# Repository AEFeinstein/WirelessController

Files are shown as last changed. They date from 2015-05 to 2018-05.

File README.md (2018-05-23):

View this project on [CADLAB.io](https://cadlab.io/project/1074). 

# WirelessController
WirelessController is an ATmega328p based video game controller that controls a [PixelShirtV2](https://github.com/AEFeinstein/PixelShirtV2), which is Arduino based collection of games, using an nRF24L01+ wireless radio.

## The Firmware

The firmware is relatively simple. The main function initializes the hardware and calibrates the joystick. An infinite loop polls the digital buttons and analog X & Y values of the joystick. If any of the values change, a bitpacked message containing the controller's state is sent to the PixelShirtV2.

A timer interrupt is called once a second to toggle a heartbeat LED.

Each controller's ID must be hardcoded differently when compiling and flashing the firmware. The PixelShirtV2 can support up to four controllers simultaneously.

This project uses the [nrf24L01+ radio library](https://github.com/kehribar/nrf24L01_plus).

## The Hardware

The controller is powered by two AA batteries, which make nice grips on the bottom. The ATmega328p is populated underneath the PCB. The 3x2 header is an ISP header, and the 6x1 header is for serial debug over an FTDI cable.

I populated one of the controllers with red LEDs, and the other with blue LEDs. These are conveniently the two player colors used in all games, which made identifying player one and player two very easy.

Screenshots of the PCB layout. The top view is first, then the bottom view.
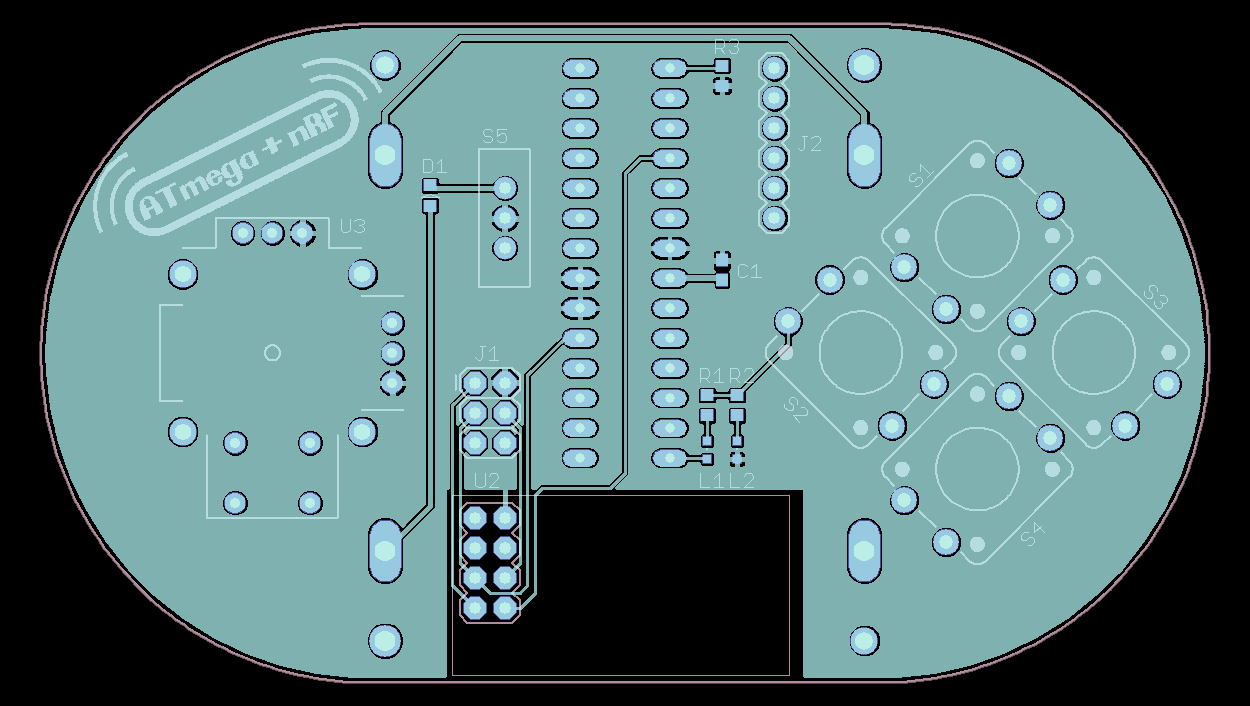
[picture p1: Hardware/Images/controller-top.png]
<br>
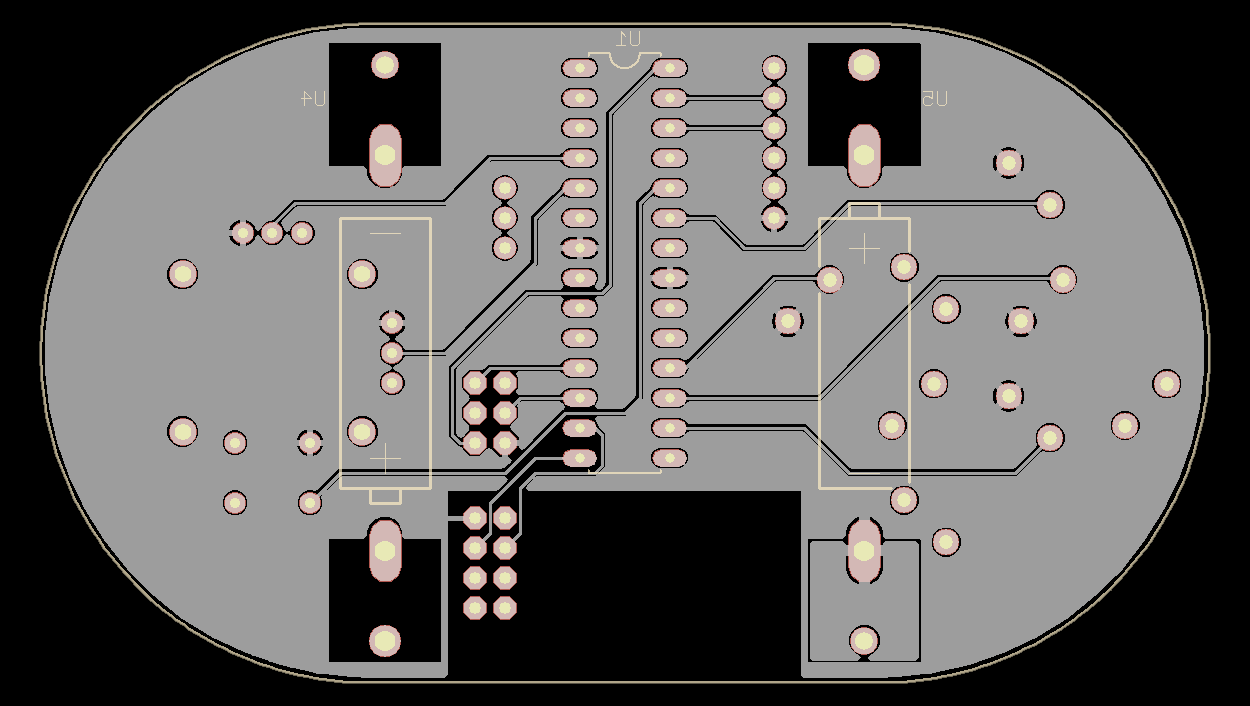
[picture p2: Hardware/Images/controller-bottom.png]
<br>

This is what it looks like all soldered together.
<br>

## Thanks
3D models and print courtesy of [gbsoares](https://github.com/gbsoares).<br>
[jgordo32](https://github.com/jgordo32) assisted with hardware design.

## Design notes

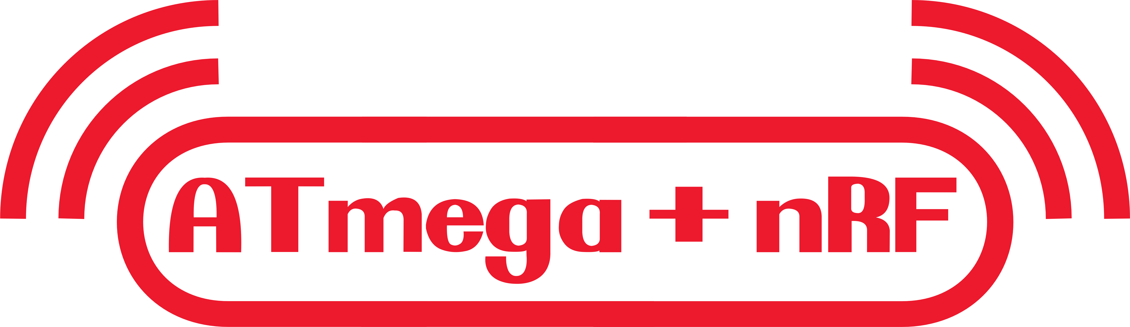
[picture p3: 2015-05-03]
Hardware/nintendo.png

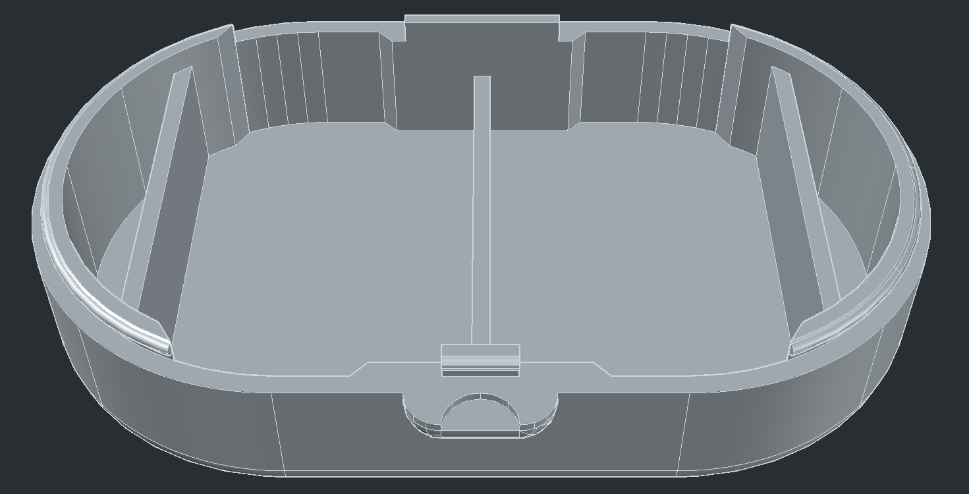
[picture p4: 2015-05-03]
Enclosure/Renderings/bottom1.png

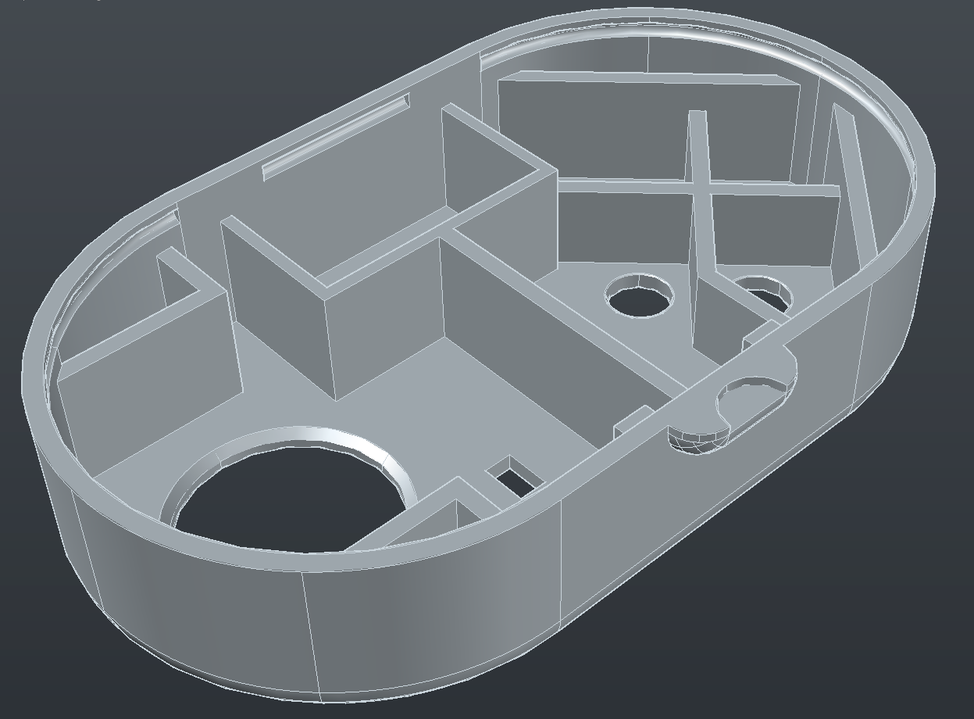
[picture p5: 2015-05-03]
Enclosure/Renderings/top3.png

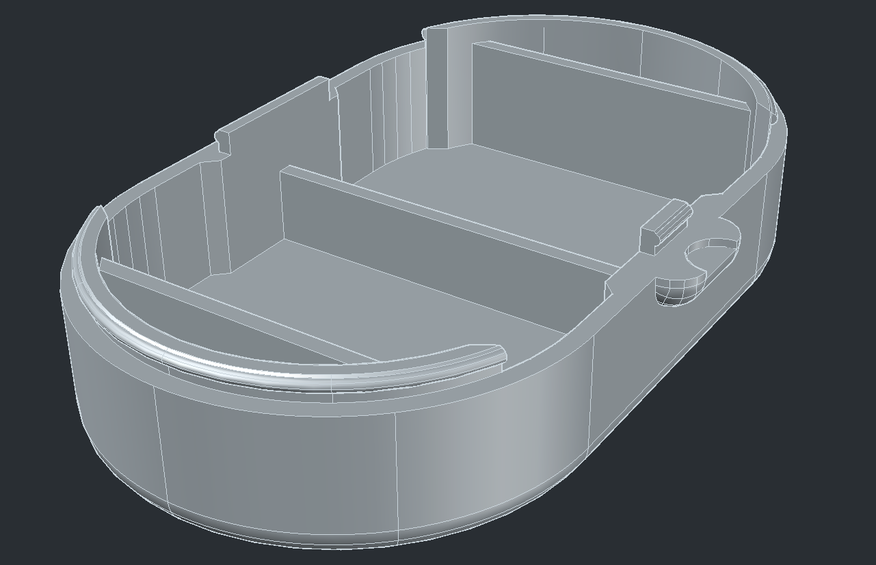
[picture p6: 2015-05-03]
Enclosure/Renderings/bottom2.png

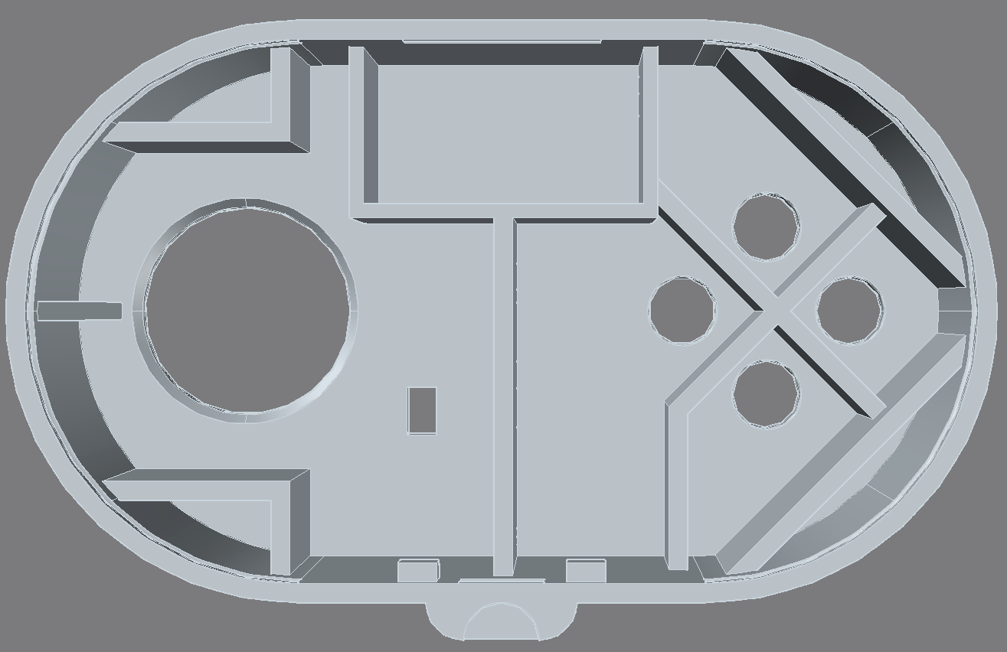
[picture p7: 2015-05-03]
Enclosure/Renderings/top2.png

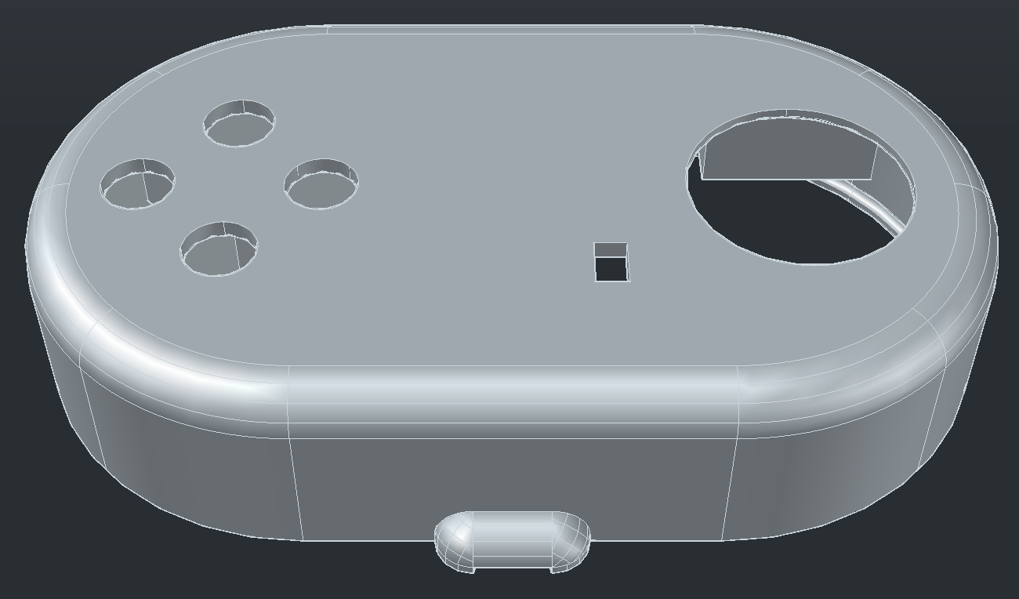
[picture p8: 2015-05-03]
Enclosure/Renderings/top1.png

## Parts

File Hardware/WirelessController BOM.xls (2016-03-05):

Cost | Quantity | Description | PCB Reference | Part Number | Link
$0.24 | 1 | DIL VERTICAL PC TAIL PIN HEADER, 3x2 | J1 | 952-2121-ND | https://www.digikey.com/product-detail/en/harwin-inc/M20-9980346/952-2121-ND/3728085
$0.24 | 1 | SIL VERTICAL PC TAIL PIN HEADER, 6x1 | J2 | 952-2270-ND | https://www.digikey.com/product-detail/en/harwin-inc/M20-9990646/952-2270-ND/3728234
$0.10 | 2 | RES SMD 30 OHM 5% 1/10W 0603 | R1, R2 | P30GCT-ND | https://www.digikey.com/product-detail/en/panasonic-electronic-components/ERJ-3GEYJ300V/P30GCT-ND/134671
$0.17 | 1 | RES SMD 4.7K OHM 1% 1/8W 0603 | R3 | MCT0603-4.70K-CFCT-ND | https://www.digikey.com/product-detail/en/vishay-beyschlag/MCT06030C4701FP500/MCT0603-4.70K-CFCT-ND/2607907
$0.38 | 2 | LED BLUE DIFFUSED 0603 SMD | L1. L2 | 475-2816-1-ND | https://www.digikey.com/product-detail/en/osram-opto-semiconductors-inc/LB%20Q39G-L2OO-35-1/475-2816-1-ND/2176355
$0.10 | 1 | CAP CER 0.1UF 16V X7R 0603 | C1 | 490-1532-1-ND | https://www.digikey.com/product-detail/en/murata-electronics-north-america/GRM188R71C104KA01D/490-1532-1-ND/587771
$0.52 | 1 | DIODE SCHOTTKY 40V 30MA 0603 | D1 | CD0603-B00340CT-ND | https://www.digikey.com/product-detail/en/bourns-inc/CD0603-B00340/CD0603-B00340CT-ND/3534223
$3.70 | 1 | IC MCU 8BIT 32KB FLASH 28PDIP | U1 | ATMEGA328P-PU-ND | https://www.digikey.com/product-detail/en/atmel/ATMEGA328P-PU/ATMEGA328P-PU-ND/1914589
$2.90 | 1 | NRF24L01+MODULE | U2 | 1597-1352-ND | https://www.digikey.com/product-detail/en/seeed-technology-ltd/113990011/1597-1352-ND/5488251
$3.95 | 1 | Thumb Joystick | U3 | COM-09032 | https://www.sparkfun.com/products/9032
$0.50 | 2 | Battery Holder - 1xAA (PTH) | U4, U5 | PRT-07949 | https://www.sparkfun.com/products/7949
$0.50 | 4 | Momentary Pushbutton Switch - 12mm Square | S1, S2, S3, S4 | COM-09190 | https://www.sparkfun.com/products/9190
$1.50 | 1 | SPDT Mini Power Switch | S5 | COM-00102 | https://www.sparkfun.com/products/102
$4.00 | 1 | Wireless Controller PCB |  |  | https://github.com/AEFeinstein/WirelessController/tree/master/Hardware
$21.28

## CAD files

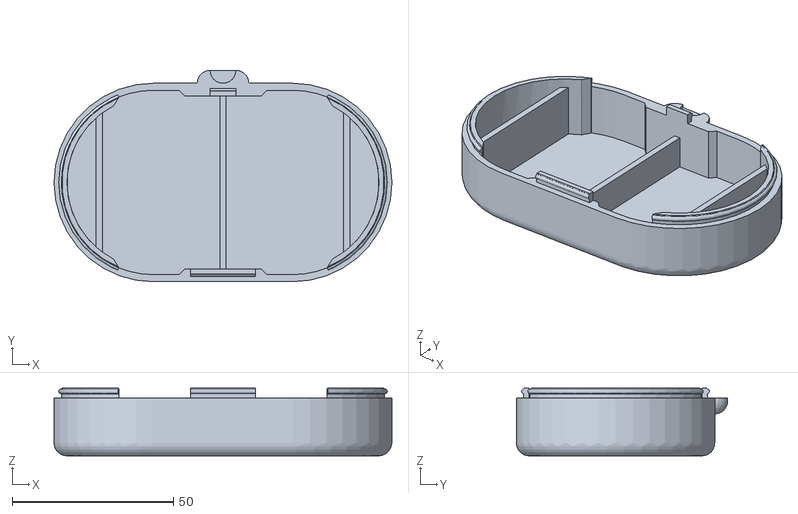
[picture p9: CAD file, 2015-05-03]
Enclosure/3D print/bottom.stl
104.7 x 65.5 x 21.0

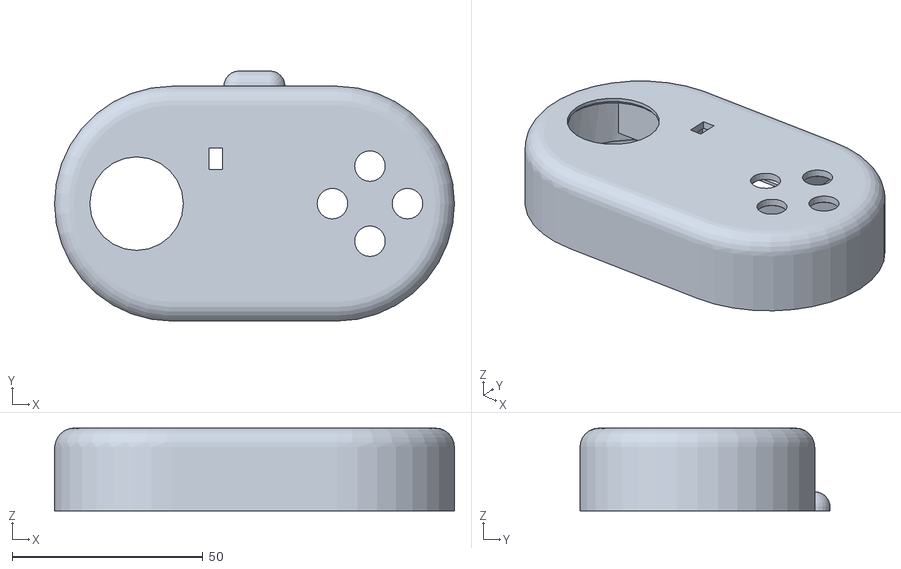
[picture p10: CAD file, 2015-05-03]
Enclosure/3D print/top.stl
104.7 x 65.5 x 21.7

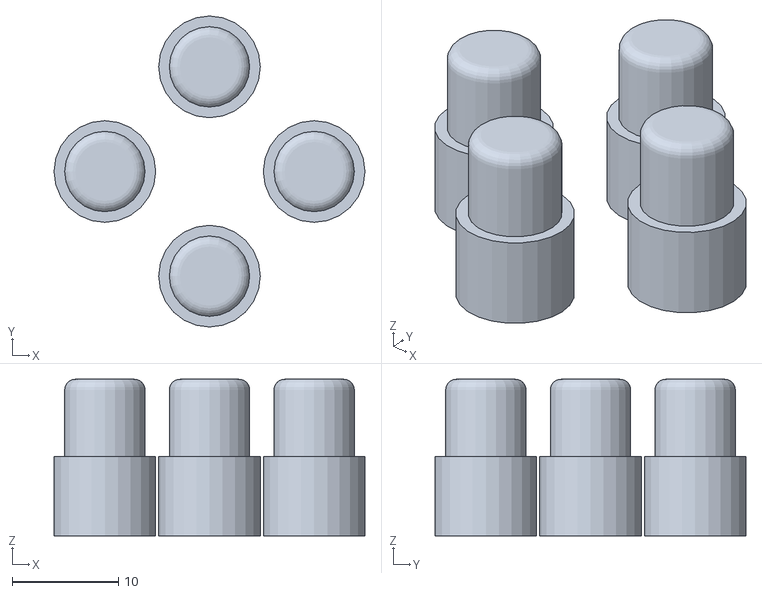
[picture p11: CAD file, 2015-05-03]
Enclosure/3D print/buttons.stl
29.2 x 29.2 x 14.7

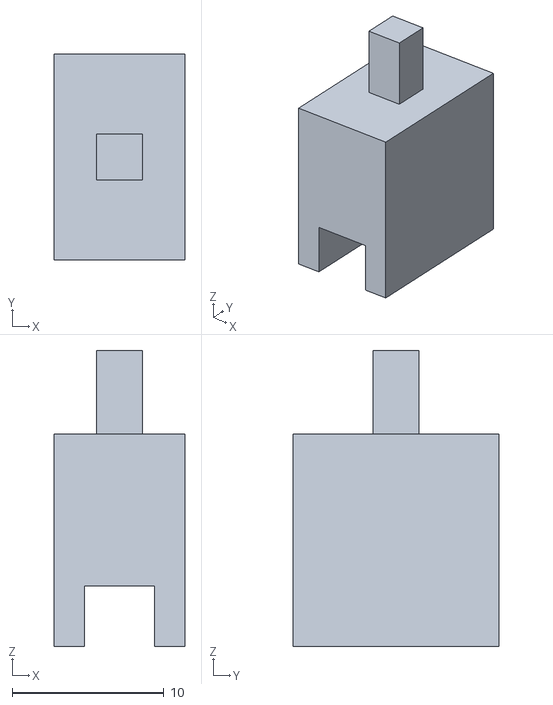
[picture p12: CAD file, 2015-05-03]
Enclosure/3D print/switch.stl
8.60 x 13.6 x 19.5

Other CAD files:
Enclosure/controller_case.dwg

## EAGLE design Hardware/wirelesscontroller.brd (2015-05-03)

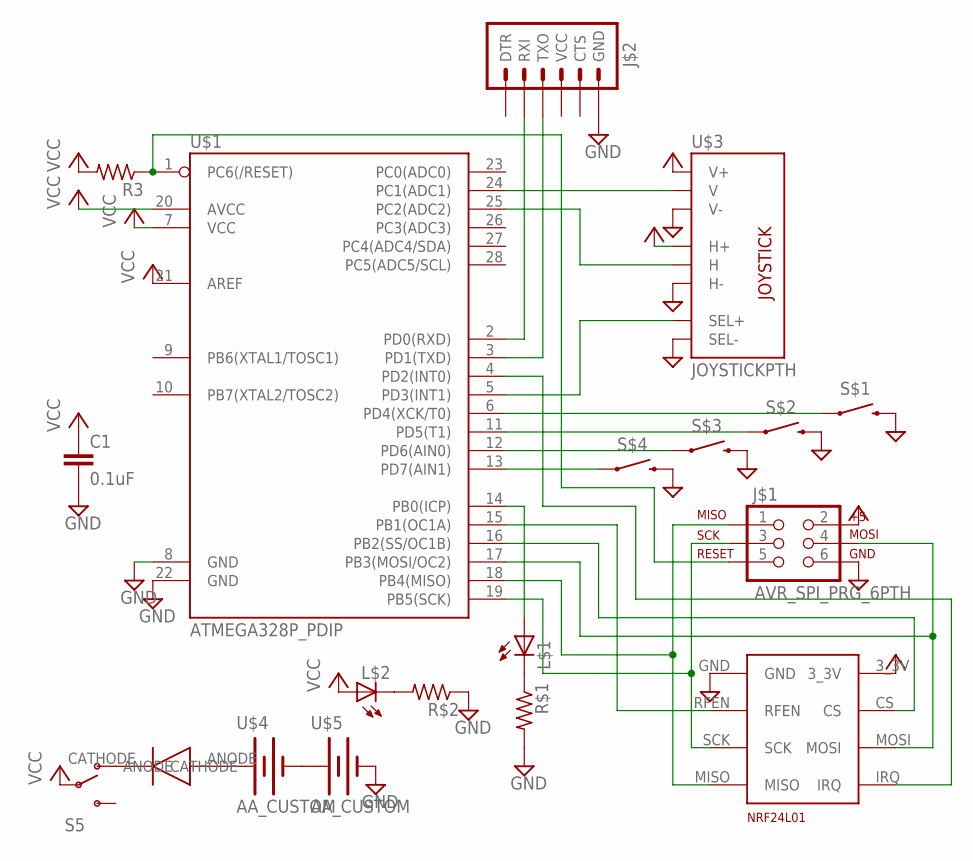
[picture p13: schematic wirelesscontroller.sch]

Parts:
C1: 0.1uF; 0603-CAP
D$1: DIODE; R0603
J$1: AVR_SPI_PRG_6PTH; 2X3
J$2: ARDUINO_SERIAL_PROGRAMPTH; 1X06
L$1, L$2: LEDCHIPLED_0603; CHIPLED_0603
R3: R-US_R0603; R0603
R$1, R$2: R-US_R0603; R0603
S5: SWITCH-SPDTPTH; SWITCH-SPDT
S$1, S$2, S$3, S$4: SWITCH-MOMENTARY-212MM; TACTILE-PTH-12MM
U$1: ATMEGA328P_PDIP; DIL28-3
U$2: NRF24L01_BRK; 4X2
U$3: JOYSTICKPTH; JOYSTICK
U$4, U$5: AA_CUSTOM; AACLIP

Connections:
AX: U$1.25 (PC2(ADC2)), U$3.H2 (H)
AY: U$1.24 (PC1(ADC1)), U$3.V2 (V)
B1: S$1.1, U$1.6 (PD4(XCK/T0))
B2: S$2.1, U$1.11 (PD5(T1))
B3: S$3.1, U$1.12 (PD6(AIN0))
B4: S$4.1, U$1.13 (PD7(AIN1))
B5: U$1.5 (PD3(INT1)), U$3.B1A (SEL+)
CS: U$1.16 (PB2(SS/OC1B)), U$2.CS
GND: C1.2, J$1.6, J$2.6 (GND), R$1.2, R$2.1, S$1.3 (2), S$2.3 (2), S$3.3 (2), S$4.3 (2), U$1.8 (GND), U$1.22 (GND), U$2.GND, U$3.B2A (SEL-), U$3.H3 (H-), U$3.V3 (V-), U$5.-
MISO: J$1.1, U$1.18 (PB4(MISO)), U$2.MISO
MOSI: J$1.4, U$1.17 (PB3(MOSI/OC2)), U$2.MOSI
unnamed: D$1.CATHODE, S5.1 (O)
unnamed: U$4.-, U$5.+
unnamed: D$1.ANODE, U$4.+
unnamed: L$2.C, R$2.2
unnamed: L$1.C, R$1.1
unnamed: L$1.A, U$1.14 (PB0(ICP))
RESET: J$1.5, R3.1, U$1.1 (PC6(/RESET))
RFEN: U$1.15 (PB1(OC1A)), U$2.RFEN
RF_IRQ: U$1.4 (PD2(INT0)), U$2.IRQ
RX: J$2.2 (RXI), U$1.2 (PD0(RXD))
SCK: J$1.3, U$1.19 (PB5(SCK)), U$2.SCK
TX: J$2.3 (TXO), U$1.3 (PD1(TXD))
VCC: C1.1, J$1.2, L$2.A, R3.2, S5.2, U$1.7 (VCC), U$1.20 (AVCC), U$1.21 (AREF), U$2.3_3V, U$3.H1 (H+), U$3.V1 (V+)

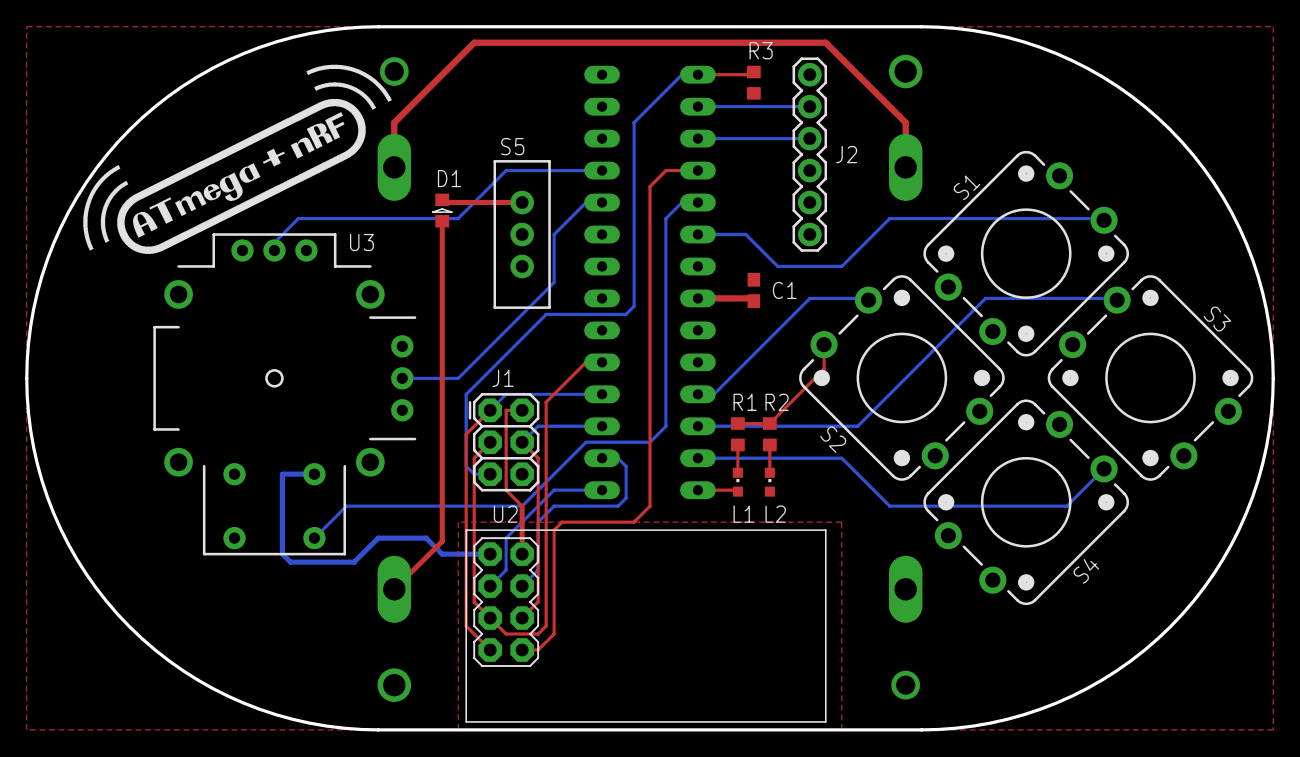
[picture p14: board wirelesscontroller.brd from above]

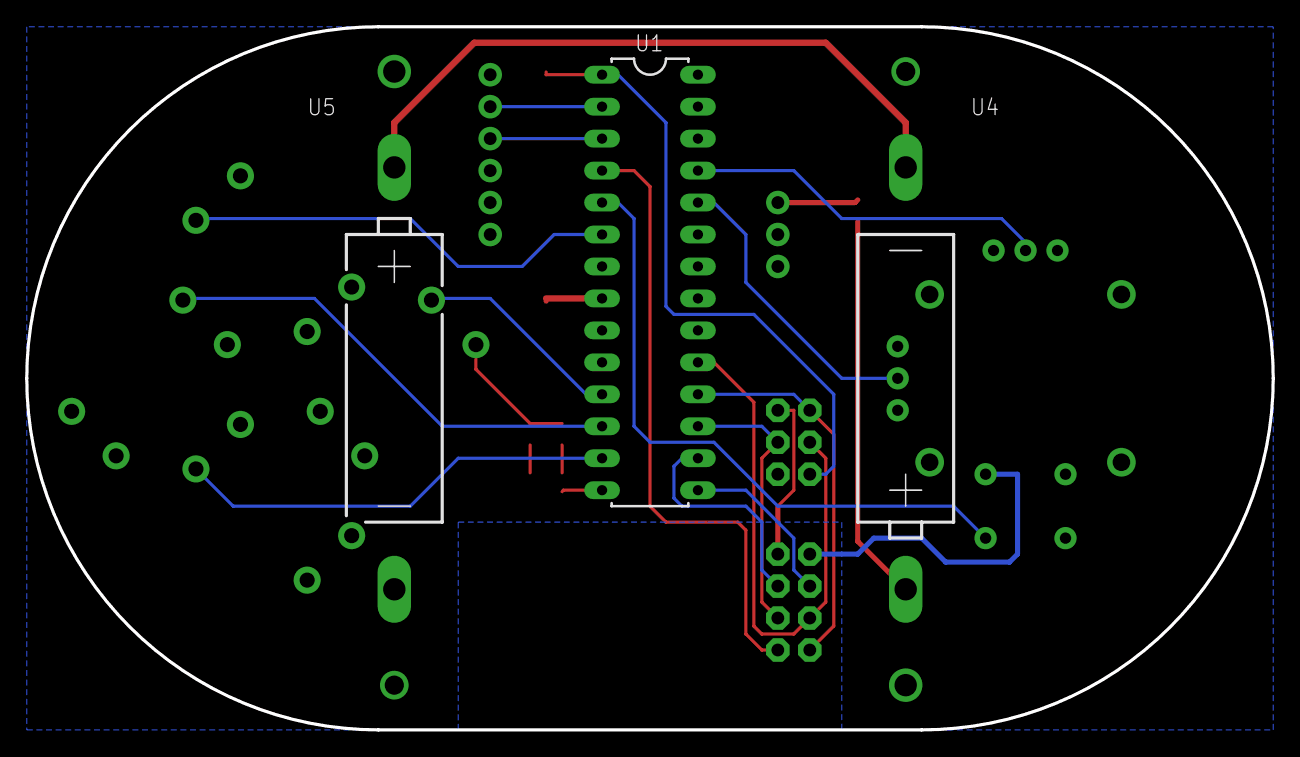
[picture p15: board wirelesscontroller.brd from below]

Board: 2 copper layers, 99.1 x 55.9 mm, 19 parts (3 on the bottom side), 24 nets.

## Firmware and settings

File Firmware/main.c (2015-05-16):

/**
 * Copyright 2011 Adam Feinstein
 *
 * This file is part of WirelessController.
 *
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
 * You should have received a copy of the GNU General Public License
 * along with WirelessController.  If not, see <http://www.gnu.org/licenses/>.
 */

#include <stdint.h>

#include "main.h"
#include "gpio.h"
#include "nrf24.h"
#include "timer.h"
#if DBG_PRINT == ENABLED
#include "uart.h"
#include <util/delay.h>
#include <string.h>
#include <stdlib.h>
#endif

/* Number of ADC reads taken to calibrate the ADC's middle position */
#define NUM_CALIBRATIONS 10

int main(void)
{
  /* All the controller state is stored in 32 bits */
  uint32_t inputState, oldInputState;

  /* Used for calibrating the ADC */
  uint32_t xJoystickCenter, yJoystickCenter;
  uint8_t i;

  #if DBG_PRINT == ENABLED
  uint8_t msgStatus;
  char dbgstr[100];
  #endif

  /* Initialize everything */
  gpio_init();
  nrf24_init();
  timer_init();
  #if DBG_PRINT == ENABLED
  init_uart();
  #endif

  /* Calibrate joystick center */
  xJoystickCenter = 0;
  yJoystickCenter = 0;
  for(i = 0; i < NUM_CALIBRATIONS; i++) {
    analog_read(&inputState, 0, 0);
    xJoystickCenter += GET_X_AXIS(inputState);
    yJoystickCenter += GET_Y_AXIS(inputState);
  }
  xJoystickCenter /= NUM_CALIBRATIONS;
  yJoystickCenter /= NUM_CALIBRATIONS;

  /* Set an ID to differentiate controllers. Must be compiled differently for controllers 1-4 */
  /* SET_PLAYER(inputState, 0); */
  SET_PLAYER(inputState, 1);
  /* SET_PLAYER(inputState, 2); */
  /* SET_PLAYER(inputState, 3); */

  /* Main Loop */
  while (1) {

    /* Save the prior state */
    oldInputState = inputState;

    /* Read Controller State */
    digital_read(&inputState);
    analog_read(&inputState, xJoystickCenter, yJoystickCenter);

    /* If any inputs have changed, send an RF message */
    if(oldInputState != inputState) {

      /* Send the controller's state. Automatically goes to TX mode */
      nrf24_send((uint8_t*)(&inputState));

      while(nrf24_isSending()) {
        ;/* Wait for transmission to end */
      }

      #if DBG_PRINT == ENABLED
      /* Make analysis on last transmission attempt */
      msgStatus = nrf24_lastMessageStatus();

      if(msgStatus == NRF24_TRANSMISSON_OK) {
        USART_putstring("transmission went OK\n");
      }
      else if(msgStatus == NRF24_MESSAGE_LOST) {
        USART_putstring("Message is lost\n");
      }

      /* Retransmission count indicates the transmission quality */
      msgStatus = nrf24_retransmissionCount();
      USART_putstring("Retransmission count: ");
      itoa(msgStatus, dbgstr, 16);
      USART_putstring(dbgstr);
      USART_putstring("\n");

      /* Print the analog stick position */
      itoa(GET_X_AXIS(inputState), dbgstr, 16);
      USART_putstring(dbgstr);
      USART_putstring(", ");
      itoa(GET_Y_AXIS(inputState), dbgstr, 16);
      USART_putstring(dbgstr);
      USART_send('\n');

      /* Print button positions */
      if(GET_BUTTONS(inputState) & UP) {
        USART_putstring("UP\n");
      }
      if(GET_BUTTONS(inputState) & DOWN) {
        USART_putstring("DOWN\n");
      }
      if(GET_BUTTONS(inputState) & LEFT) {
        USART_putstring("LEFT\n");
      }
      if(GET_BUTTONS(inputState) & RIGHT) {
        USART_putstring("RIGHT\n");
      }
      if(GET_BUTTONS(inputState) & STICK) {
        USART_putstring("STICK\n");
      }
      USART_send('\n');
      #endif
    }
  }
  return (0);
}

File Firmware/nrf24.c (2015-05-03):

/*
* ----------------------------------------------------------------------------
* THE COFFEEWARE LICENSE (Revision 1):
* <ihsan@kehribar.me> wrote this file. As long as you retain this notice you
* can do whatever you want with this stuff. If we meet some day, and you think
* this stuff is worth it, you can buy me a coffee in return.
* -----------------------------------------------------------------------------
* This library is based on this library:
*   https://github.com/aaronds/arduino-nrf24l01
* Which is based on this library:
*   http://www.tinkerer.eu/AVRLib/nRF24L01
* -----------------------------------------------------------------------------
*/
#include "nrf24.h"

uint8_t payload_len;

uint8_t rx_address[5] = {0xD7, 0xD7, 0xD7, 0xD7, 0xD7};
uint8_t tx_address[5] = {0xE7, 0xE7, 0xE7, 0xE7, 0xE7};

/* init the hardware pins */
void nrf24_init()
{
  nrf24_setupPins();
  nrf24_ce_digitalWrite(LOW);
  nrf24_csn_digitalWrite(HIGH);

  /* Channel #2 , payload length: 4 */
  nrf24_config(2, 4);

  /* Set the device addresses */
  nrf24_tx_address(tx_address);
  nrf24_rx_address(rx_address);
}

/* configure the module */
void nrf24_config(uint8_t channel, uint8_t pay_length)
{
  /* Use static payload length ... */
  payload_len = pay_length;

  // Set RF channel
  nrf24_configRegister(RF_CH,channel);

  // Set length of incoming payload
  nrf24_configRegister(RX_PW_P0, 0x00); // Auto-ACK pipe ...
  nrf24_configRegister(RX_PW_P1, payload_len); // Data payload pipe
  nrf24_configRegister(RX_PW_P2, 0x00); // Pipe not used
  nrf24_configRegister(RX_PW_P3, 0x00); // Pipe not used
  nrf24_configRegister(RX_PW_P4, 0x00); // Pipe not used
  nrf24_configRegister(RX_PW_P5, 0x00); // Pipe not used

  // 1 Mbps, TX gain: 0dbm
  nrf24_configRegister(RF_SETUP, (0<<RF_DR)|((0x03)<<RF_PWR));

  // CRC enable, 1 byte CRC length
  nrf24_configRegister(CONFIG,nrf24_CONFIG);

  // Auto Acknowledgment
  nrf24_configRegister(EN_AA,
                       (1<<ENAA_P0)|(1<<ENAA_P1)|(0<<ENAA_P2)|(0<<ENAA_P3)|(0<<ENAA_P4)|(0<<ENAA_P5));

  // Enable RX addresses
  nrf24_configRegister(EN_RXADDR,
                       (1<<ERX_P0)|(1<<ERX_P1)|(0<<ERX_P2)|(0<<ERX_P3)|(0<<ERX_P4)|(0<<ERX_P5));

  // Auto retransmit delay: 1000 us and Up to 15 retransmit trials
  nrf24_configRegister(SETUP_RETR,(0x04<<ARD)|(0x0F<<ARC));

  // Dynamic length configurations: No dynamic length
  nrf24_configRegister(DYNPD,
                       (0<<DPL_P0)|(0<<DPL_P1)|(0<<DPL_P2)|(0<<DPL_P3)|(0<<DPL_P4)|(0<<DPL_P5));

  // Start listening
  nrf24_powerUpRx();
}

/* Set the RX address */
void nrf24_rx_address(uint8_t* adr)
{
  nrf24_ce_digitalWrite(LOW);
  nrf24_writeRegister(RX_ADDR_P1,adr,nrf24_ADDR_LEN);
  nrf24_ce_digitalWrite(HIGH);
}

/* Returns the payload length */
uint8_t nrf24_payload_length()
{
  return payload_len;
}

/* Set the TX address */
void nrf24_tx_address(uint8_t* adr)
{
  /* RX_ADDR_P0 must be set to the sending addr for auto ack to work. */
  nrf24_writeRegister(RX_ADDR_P0,adr,nrf24_ADDR_LEN);
  nrf24_writeRegister(TX_ADDR,adr,nrf24_ADDR_LEN);
}

/* Checks if data is available for reading */
/* Returns 1 if data is ready ... */
uint8_t nrf24_dataReady()
{
  // See note in getData() function - just checking RX_DR isn't good enough
  uint8_t status = nrf24_getStatus();

  // We can short circuit on RX_DR, but if it's not set, we still need
  // to check the FIFO for any pending packets
  if ( status & (1 << RX_DR) ) {
    return 1;
  }

  return !nrf24_rxFifoEmpty();;
}

/* Checks if receive FIFO is empty or not */
uint8_t nrf24_rxFifoEmpty()
{
  uint8_t fifoStatus;

  nrf24_readRegister(FIFO_STATUS,&fifoStatus,1);

  return (fifoStatus & (1 << RX_EMPTY));
}

/* Returns the length of data waiting in the RX fifo */
uint8_t nrf24_payloadLength()
{
  uint8_t status;
  nrf24_csn_digitalWrite(LOW);
  spi_transfer(R_RX_PL_WID);
  status = spi_transfer(0x00);
  nrf24_csn_digitalWrite(HIGH);
  return status;
}

/* Reads payload bytes into data array */
void nrf24_getData(uint8_t* data)
{
  /* Pull down chip select */
  nrf24_csn_digitalWrite(LOW);

  /* Send cmd to read rx payload */
  spi_transfer( R_RX_PAYLOAD );

  /* Read payload */
  nrf24_transferSync(data,data,payload_len);

  /* Pull up chip select */
  nrf24_csn_digitalWrite(HIGH);

  /* Reset status register */
  nrf24_configRegister(STATUS,(1<<RX_DR));
}

/* Returns the number of retransmissions occured for the last message */
uint8_t nrf24_retransmissionCount()
{
  uint8_t rv;
  nrf24_readRegister(OBSERVE_TX,&rv,1);
  rv = rv & 0x0F;
  return rv;
}

// Sends a data package to the default address. Be sure to send the correct
// amount of bytes as configured as payload on the receiver.
void nrf24_send(uint8_t* value)
{
  /* Go to Standby-I first */
  nrf24_ce_digitalWrite(LOW);

  /* Set to transmitter mode , Power up if needed */
  nrf24_powerUpTx();

  /* Do we really need to flush TX fifo each time ? */
  #if 1
  /* Pull down chip select */
  nrf24_csn_digitalWrite(LOW);

  /* Write cmd to flush transmit FIFO */
  spi_transfer(FLUSH_TX);

  /* Pull up chip select */
  nrf24_csn_digitalWrite(HIGH);
  #endif

  /* Pull down chip select */
  nrf24_csn_digitalWrite(LOW);

  /* Write cmd to write payload */
  spi_transfer(W_TX_PAYLOAD);

  /* Write payload */
  nrf24_transmitSync(value,payload_len);

  /* Pull up chip select */
  nrf24_csn_digitalWrite(HIGH);

  /* Start the transmission */
  nrf24_ce_digitalWrite(HIGH);
}

uint8_t nrf24_isSending()
{
  uint8_t status;

  /* read the current status */
  status = nrf24_getStatus();

  /* if sending successful (TX_DS) or max retries exceded (MAX_RT). */
  if((status & ((1 << TX_DS)  | (1 << MAX_RT)))) {
    return 0; /* false */
  }

  return 1; /* true */

}

uint8_t nrf24_getStatus()
{
  uint8_t rv;
  nrf24_csn_digitalWrite(LOW);
  rv = spi_transfer(NOP);
  nrf24_csn_digitalWrite(HIGH);
  return rv;
}

uint8_t nrf24_lastMessageStatus()
{
  uint8_t rv;

  rv = nrf24_getStatus();

  /* Transmission went OK */
  if((rv & ((1 << TX_DS)))) {
    return NRF24_TRANSMISSON_OK;
  }
  /* Maximum retransmission count is reached */
  /* Last message probably went missing ... */
  else if((rv & ((1 << MAX_RT)))) {
    return NRF24_MESSAGE_LOST;
  }
  /* Probably still sending ... */
  else {
    return 0xFF;
  }
}

void nrf24_powerUpRx()
{
  nrf24_csn_digitalWrite(LOW);
  spi_transfer(FLUSH_RX);
  nrf24_csn_digitalWrite(HIGH);

  nrf24_configRegister(STATUS,(1<<RX_DR)|(1<<TX_DS)|(1<<MAX_RT));

  nrf24_ce_digitalWrite(LOW);
  nrf24_configRegister(CONFIG,nrf24_CONFIG|((1<<PWR_UP)|(1<<PRIM_RX)));
  nrf24_ce_digitalWrite(HIGH);
}

void nrf24_powerUpTx()
{
  nrf24_configRegister(STATUS,(1<<RX_DR)|(1<<TX_DS)|(1<<MAX_RT));

  nrf24_configRegister(CONFIG,nrf24_CONFIG|((1<<PWR_UP)|(0<<PRIM_RX)));
}

void nrf24_powerDown()
{
  nrf24_ce_digitalWrite(LOW);
  nrf24_configRegister(CONFIG,nrf24_CONFIG);
}
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

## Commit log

2015-05-03 Added initial project files
    [bottom.stl, buttons.stl, controller_case.dwg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]
2016-03-05 Added BOM
    [WirelessController BOM.xls]

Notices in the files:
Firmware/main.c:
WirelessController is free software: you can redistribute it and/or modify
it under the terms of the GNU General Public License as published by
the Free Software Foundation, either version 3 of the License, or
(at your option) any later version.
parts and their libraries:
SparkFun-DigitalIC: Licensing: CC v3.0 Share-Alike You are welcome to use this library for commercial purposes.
